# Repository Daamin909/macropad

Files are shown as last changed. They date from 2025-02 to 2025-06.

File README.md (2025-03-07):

# Daamin's ShrekPad

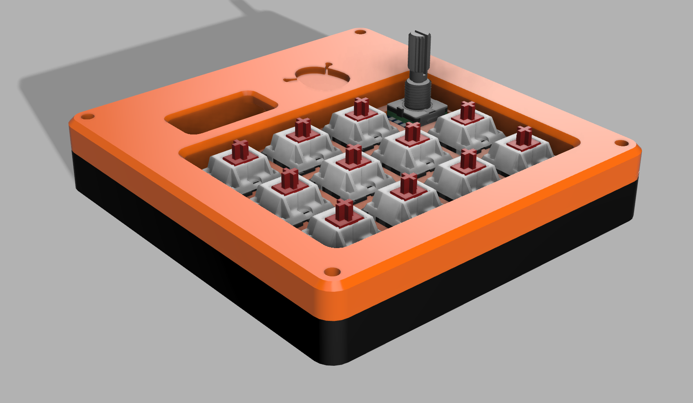
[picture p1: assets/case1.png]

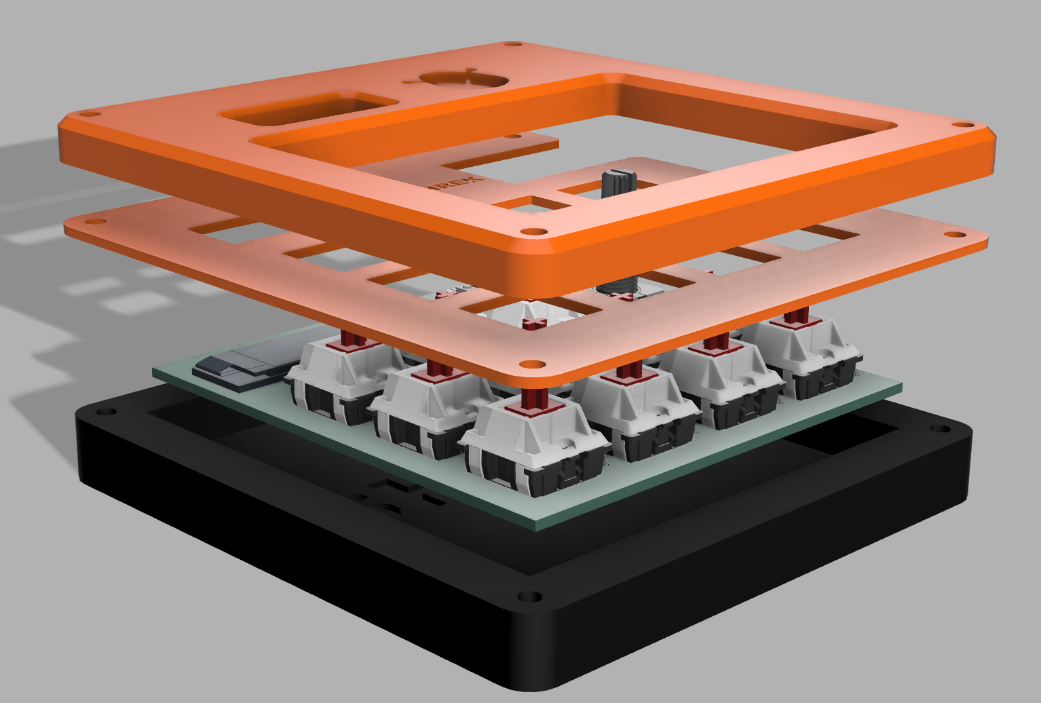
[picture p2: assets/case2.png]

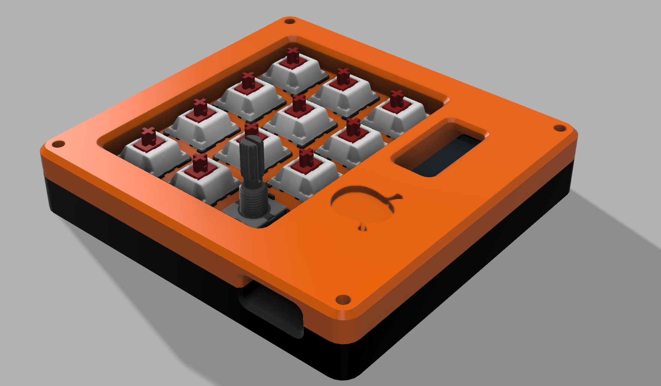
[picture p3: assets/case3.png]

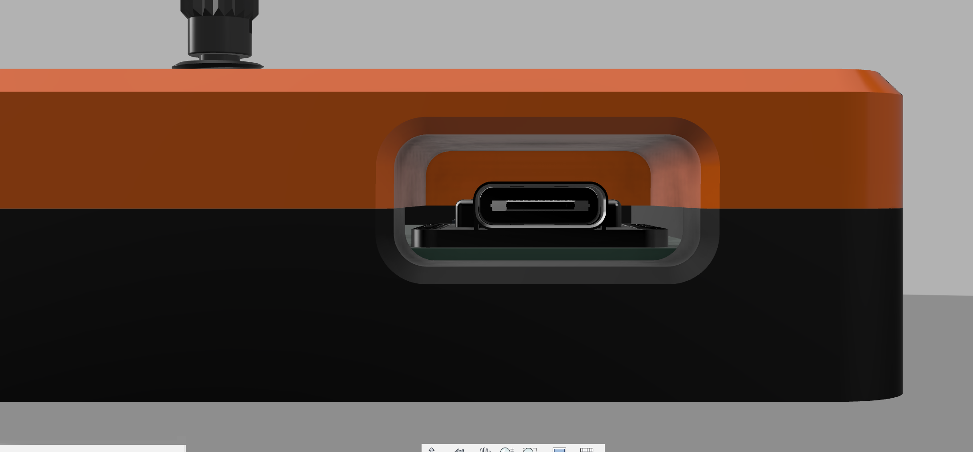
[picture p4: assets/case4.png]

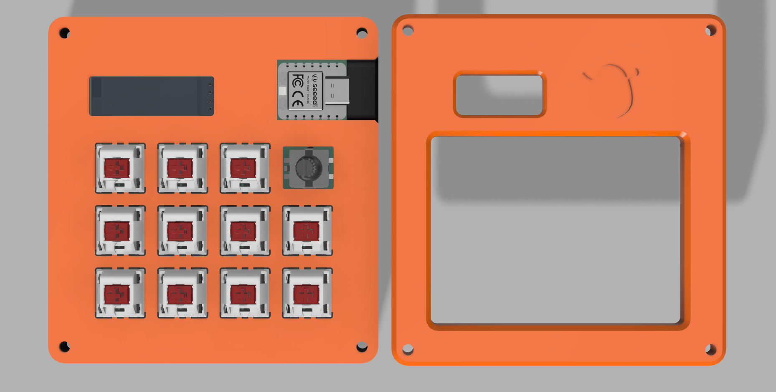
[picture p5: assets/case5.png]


### Inspiration

I wanted to boost my productivity and add an aesthetic looking device to my desk setup.

### Challenges

Believe it or not, this was my first time using Fusion 360! I spammed ChatGPT and #hackpad with queries. It also took me a lotta time making the PCB and routing it 😭. I had to reroute a hundred times.

### Case

The case features a very hot Orange and Black look with the keycaps being black and Knob being orange too.

Branding: There is a "Shrek" engraving on both the bottom and middle plate. The top case features an engraving of Shrek's face.

Thickness

- Top: 7mm
- Middle: 1.5mm
- Bottom: 11.5mm
- **Total:** 20mm

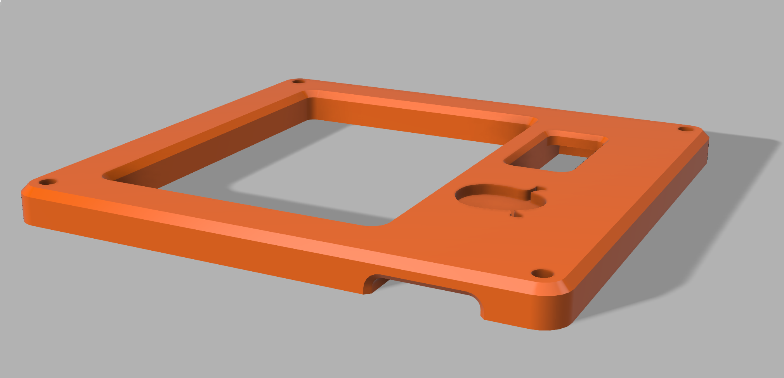
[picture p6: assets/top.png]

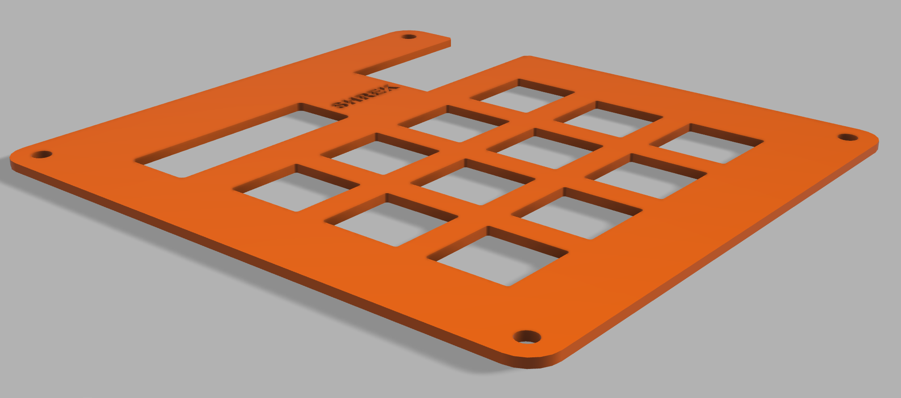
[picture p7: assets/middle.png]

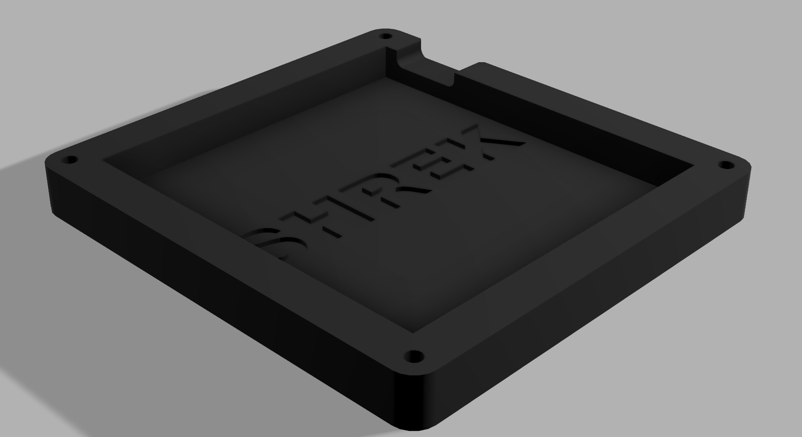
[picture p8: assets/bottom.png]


### Specifications

BOM:

- 11x Blank DSA Keycaps (11x Black)
- 11x Cherry MX Switches
- 12x 1N4148 diodes
- 1x XIAO RP2040
- 4x M3x20 Bolt ([not available at HQ? if not, then buy from here.](https://amzn.in/d/27J4X2p))
- 4x M3 Nuts
- 4x M3 Heatset
- 1x SSD1306 128x32 0.91" OLED (5V VCC, 3.3V logic, I2C)
- 1x EC11 Rotary Encoder
- 1x Rotary Encoder Knob
- 1x PCB (Please choose "Black" color while ordering 🙃)
- 1x Case (I would like both the TOP and MIDDLE to be printed in Orange and BOTTOM in Black, if not available: Message me @Daamin on Slack)

Others:

- KMK Firmware
- TOP.step
- MIDDLE.step
- BOTTOM.step

| Schematic | PCB | Case |
| :---: | :---: | :---: |
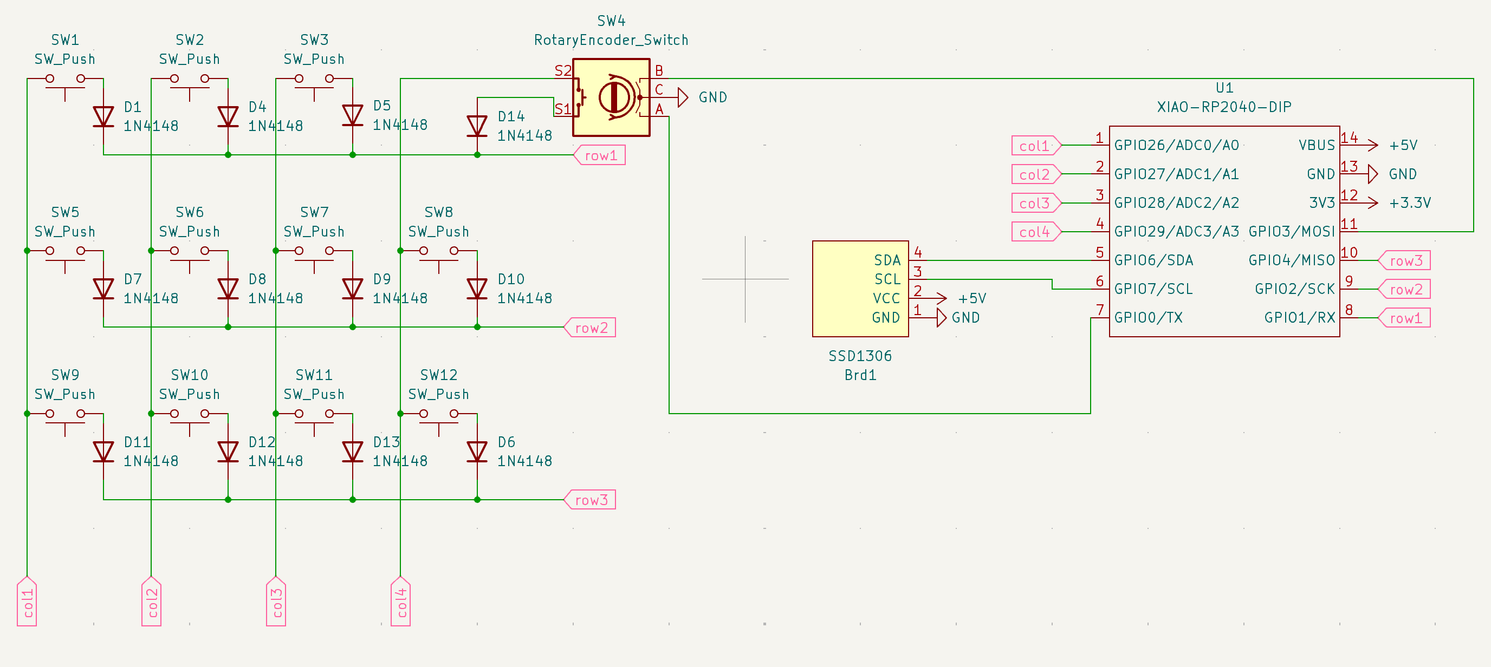
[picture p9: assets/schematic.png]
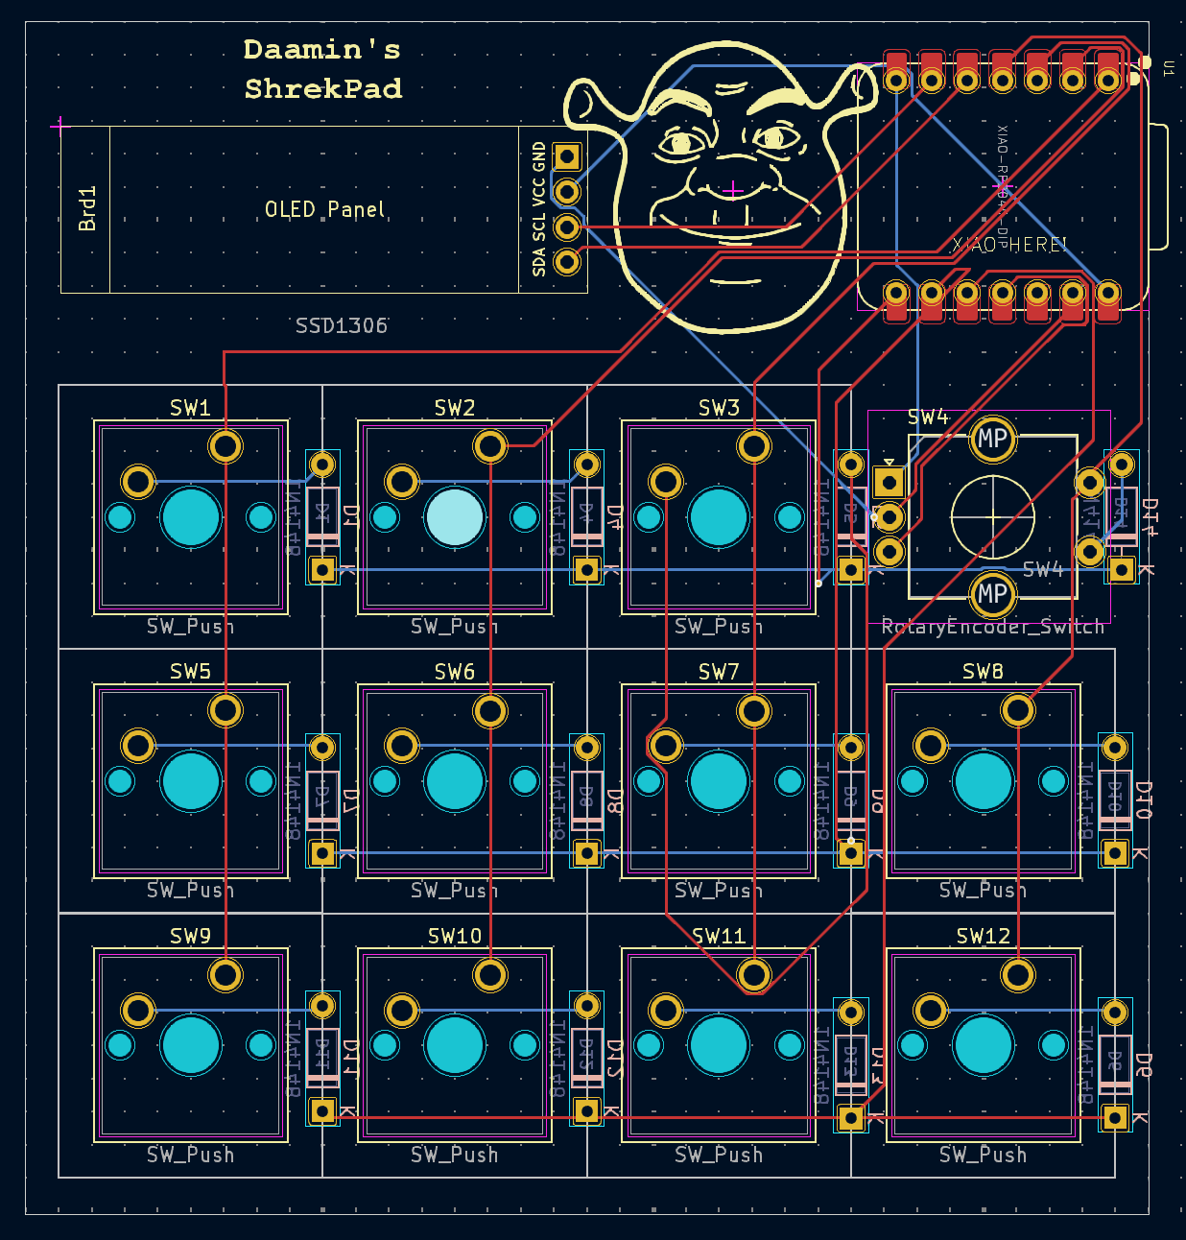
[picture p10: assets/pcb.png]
|  |  |  |

Notes:
Top and Middle printed in Orange, Bottom with Black.
PCB Color has to be black too.

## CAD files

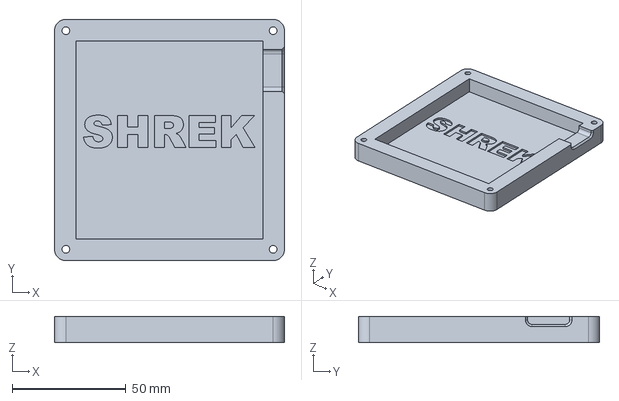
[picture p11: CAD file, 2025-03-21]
Production/BOTTOM.step
101.0 x 106.0 x 11.5 mm

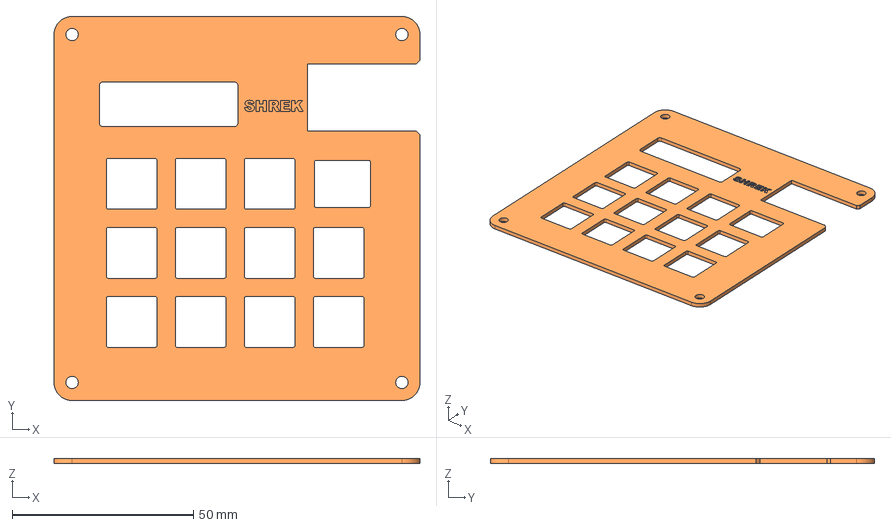
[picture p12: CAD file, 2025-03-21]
Production/MIDDLE.step
101.0 x 106.0 x 1.50 mm

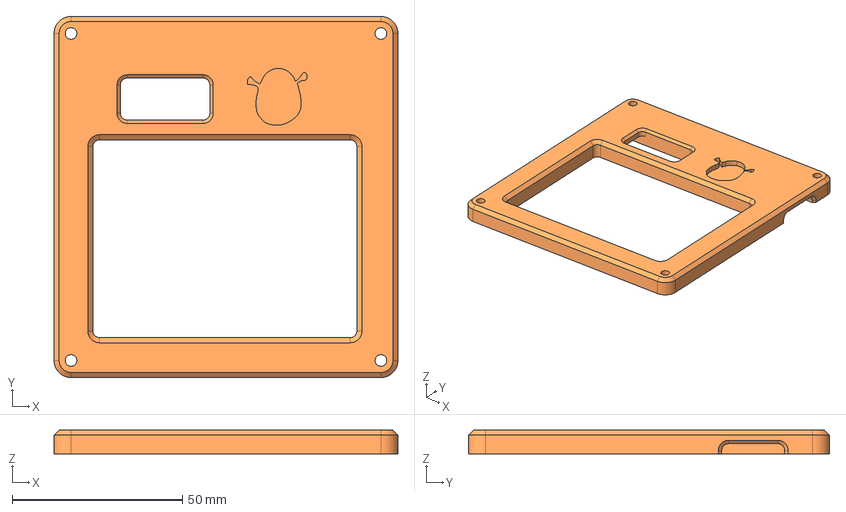
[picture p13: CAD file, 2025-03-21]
Production/TOP.step
101.0 x 106.0 x 7.00 mm

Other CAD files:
STL/BOTTOM.stl
STL/MIDDLE.stl
STL/TOP.stl

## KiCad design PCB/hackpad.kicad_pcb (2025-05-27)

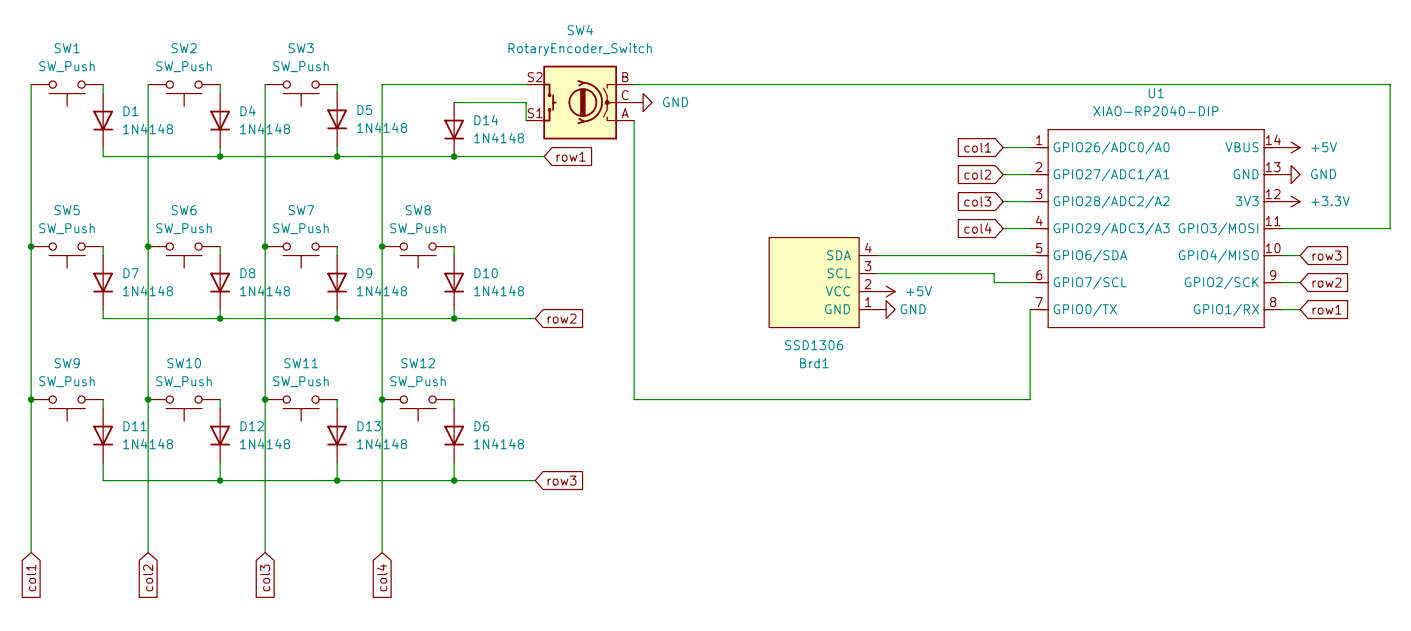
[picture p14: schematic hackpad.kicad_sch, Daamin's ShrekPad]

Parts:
Brd1: SSD1306; 128x64OLED
D1, D4, D5, D6, D7, D8, D9, D10, D11, D12, D13, D14: 1N4148; D_DO-35_SOD27_P7.62mm_Horizontal
SW1, SW2, SW3, SW5, SW6, SW7, SW8, SW9, SW10, SW11, SW12: SW_Push; SW_Cherry_MX_1.00u_PCB
SW4: RotaryEncoder_Switch; RotaryEncoder_Alps_EC11E-Switch_Vertical_H20mm_CircularMoun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
U1: XIAO-RP2040-DIP

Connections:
+3.3V: U1.12 (3V3)
+5V: Brd1.2 (VCC), U1.14 (VBUS)
GND: Brd1.1 (GND), SW4.C, U1.13 (GND)
unnamed: Brd1.3 (SCL), U1.6 (GPIO7/SCL)
unnamed: Brd1.4 (SDA), U1.5 (GPIO6/SDA)
unnamed: D1.2 (A), SW1.2
unnamed: D4.2 (A), SW2.2
unnamed: D5.2 (A), SW3.2
unnamed: D6.2 (A), SW12.2
unnamed: D7.2 (A), SW5.2
unnamed: D8.2 (A), SW6.2
unnamed: D9.2 (A), SW7.2
unnamed: D10.2 (A), SW8.2
unnamed: D11.2 (A), SW9.2
unnamed: D12.2 (A), SW10.2
unnamed: D13.2 (A), SW11.2
unnamed: D14.2 (A), SW4.S1
unnamed: SW4.A, U1.7 (GPIO0/TX)
unnamed: SW4.B, U1.11 (GPIO3/MOSI)
col1: SW1.1, SW5.1, SW9.1, U1.1 (GPIO26/ADC0/A0)
col2: SW2.1, SW6.1, SW10.1, U1.2 (GPIO27/ADC1/A1)
col3: SW3.1, SW7.1, SW11.1, U1.3 (GPIO28/ADC2/A2)
col4: SW4.S2, SW8.1, SW12.1, U1.4 (GPIO29/ADC3/A3)
row1: D1.1 (K), D4.1 (K), D5.1 (K), D14.1 (K), U1.8 (GPIO1/RX)
row2: D7.1 (K), D8.1 (K), D9.1 (K), D10.1 (K), U1.9 (GPIO2/SCK)
row3: D6.1 (K), D11.1 (K), D12.1 (K), D13.1 (K), U1.10 (GPIO4/MISO)

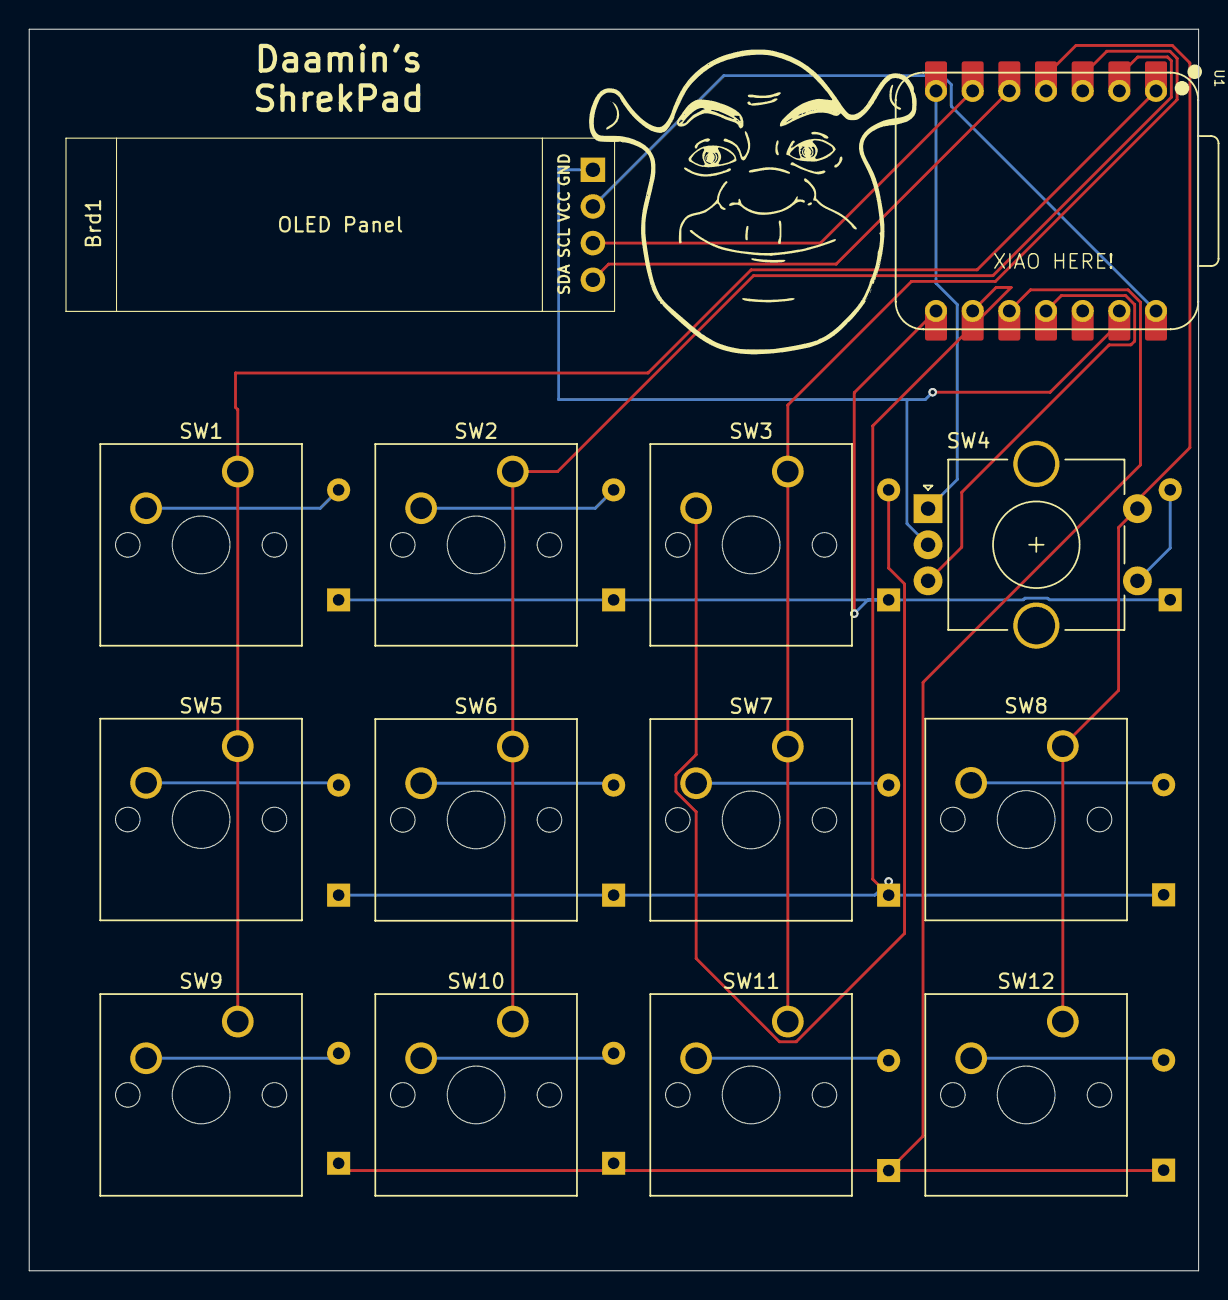
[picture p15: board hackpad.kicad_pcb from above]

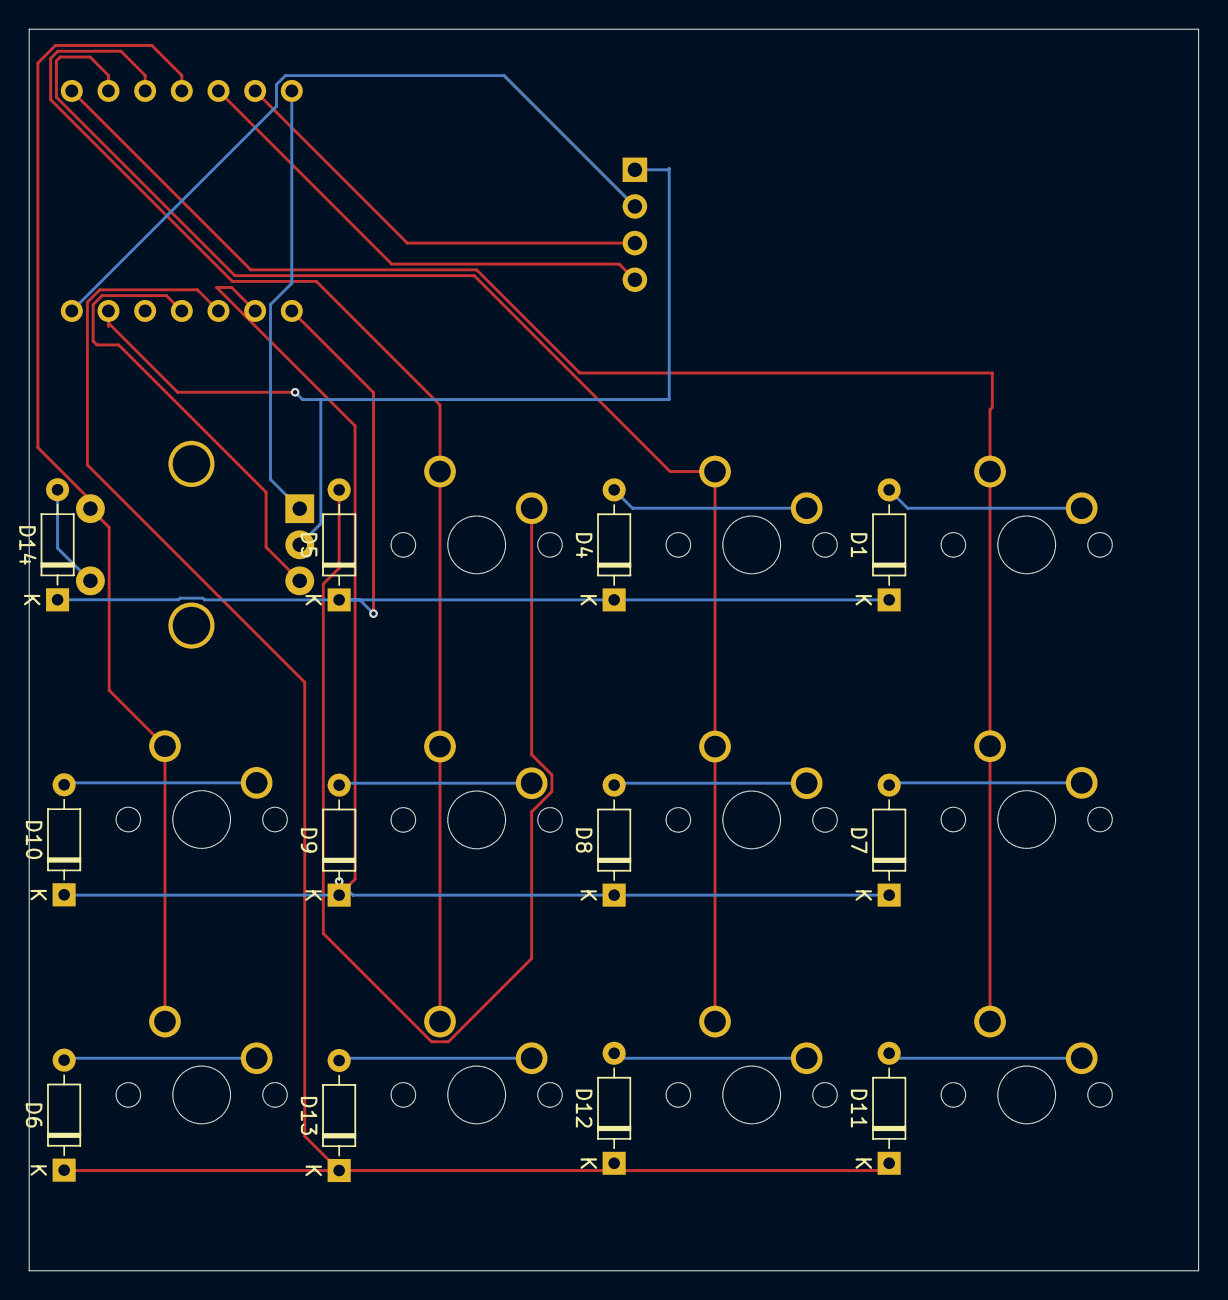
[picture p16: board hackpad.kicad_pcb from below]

Board: 2 copper layers, 81.0 x 86.0 mm, 26 parts (12 on the bottom side), 25 nets.

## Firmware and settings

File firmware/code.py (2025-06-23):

# Daamin's macropad firmware
# Rev 1.1
# Copyright 2024
# Licensed under zlib license
import board
import busio

from kmk.kmk_keyboard import KMKKeyboard
from kmk.keys import KC
from kmk.scanners import DiodeOrientation
from kmk.modules.macros import Macros, Press, Release, Tap
from kmk.modules.encoder import EncoderHandler
from kmk.extensions.media_keys import MediaKeys
from kmk.modules.mouse_keys import MouseKeys


ROTA = board.D6
ROTB = board.D10
COL1 = board.D0
COL2 = board.D1
COL3 = board.D2
COL4 = board.D3
ROW1 = board.D9
ROW2 = board.D8
ROW3 = board.D7


keyboard = KMKKeyboard()

encoder_handler = EncoderHandler()
keyboard.modules.append(MediaKeys())
keyboard.modules.append(MouseKeys())
encoder_handler.pins = ((ROTA, ROTB, None),)
encoder_handler.map = [((KC.VOLU, KC.VOLD),), ]  

macros = Macros()
keyboard.modules.append(macros)
keyboard.modules.append(encoder_handler)


keyboard.col_pins = (COL1, COL2, COL3, COL4)
keyboard.row_pins = (ROW1, ROW2, ROW3)
keyboard.diode_orientation = DiodeOrientation.COL2ROW


OPEN_VSC = KC.MACRO(Press(KC.LGUI), Tap(KC.SPACE), Release(KC.LGUI), "vsc", Tap(KC.ENTER))
OPEN_SPOTIFY = KC.MACRO(Press(KC.LGUI), Tap(KC.SPACE), Release(KC.LGUI), "spotify", Tap(KC.ENTER))
OPEN_BRAVE = KC.MACRO(Press(KC.LGUI), Tap(KC.SPACE), Release(KC.LGUI), "brave", Tap(KC.ENTER))
OPEN_DISCORD = KC.MACRO(Press(KC.LGUI), Tap(KC.SPACE), Release(KC.LGUI), "discord", Tap(KC.ENTER))
MISSION_CTRL = KC.MACRO(
    Press(KC.LALT),
    Press(KC.LSHIFT),
    Tap(KC.M),
    Release(KC.LSHIFT),
    Release(KC.LALT),
)
keyboard.keymap = [
    [KC.MRWD, KC.MFFD, KC.MW_UP, KC.LGUI(KC.V), OPEN_BRAVE, MISSION_CTRL, KC.MW_DN, KC.LGUI(KC.C), OPEN_VSC, OPEN_SPOTIFY, OPEN_DISCORD, KC.MPLY]
]

if __name__ == '__main__':
    keyboard.go()

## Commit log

2025-02-19 Added Case 3D Model, PCB and Schematic
    [BOTTOM.step, TOP.step, hackpad.kicad_pcb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]
2025-03-07 add top case to hackpad
    [BOTTOM.step, MIDDLE.step, TOP.step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]
2025-03-21 improved tolerances, recompile CAD
    [BOTTOM.step, MIDDLE.step, TOP.step]
2025-03-22 added STL files
    [BOTTOM.stl, MIDDLE.stl, TOP.stl]
2025-05-27 minor via placement change
    [hackpad.kicad_pcb]
